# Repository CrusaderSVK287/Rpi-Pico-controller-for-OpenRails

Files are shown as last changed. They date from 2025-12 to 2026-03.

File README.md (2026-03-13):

# Rpi-Pico-controller-for-OpenRails
Raspberry Pi Pico custom HID controller for OpenRails. Basically I made a custom controller for openrails
using Rpi Pico board as the central microcomputer. Since the Rpi Pico has limited analog inputs, I had to cut some 
corners. This repository contains:

- Code for the Raspberry Pi Pico.
- CAD files with the controller design.
- Any manual or documentation I have done.

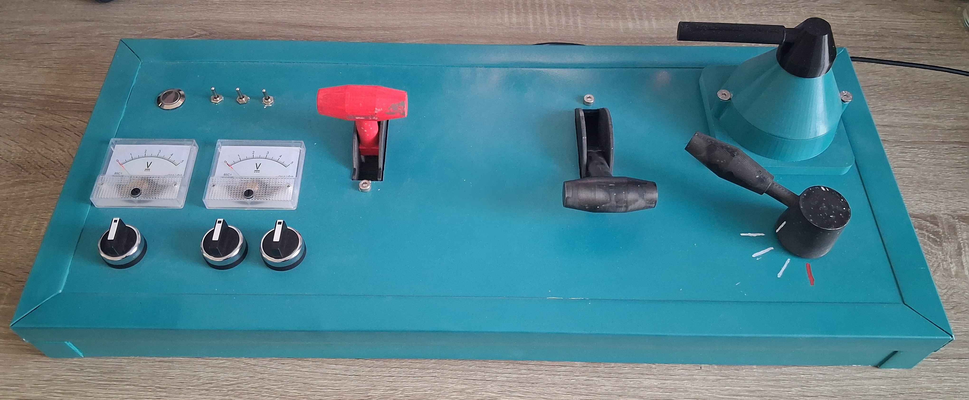
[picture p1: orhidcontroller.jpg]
Photo of the controller San Juan Mountains


## Supported controls

The controller's layout and looks is highly inspired by Czechoslovak locomotives from the 1970'-90' [For example the 754 series](https://cs.wikipedia.org/wiki/Lokomotiva_754)

### Analog controls
- Direction: the red lever, controlls the reverser of the train.
- Throttle : the black lever next to the direction lever, controls the throttle.
- Engine break: The small lever on top of the cone, controlls the engine break.

### Digital controls
- Train brake: the lever in the lower right corner. OpenRails implements train brake as analog, but due to the fact that Rpi Pico has only 3 analog inputs, I had to do this one digitaly and then just simulate it.
- Pantograph controls: turns on and off pantograph 1 and 2
- Headlights.
- Pause button: also acts as a switch TCS mode button if you run a red signal.
- View switch: 3-state switch, providing default cab view, outside static view and outside sidetrack "cinematic" view.
- Next station monitor switch.
- Track monitor switch.

# Aditional software that is needed

The OpenRails modification that includes code that interprets the HID controller is in [this repository](https://github.com/CrusaderSVK287/openrails).
<br>
In addition I made a simple app to test whether the controller is working properly, [here](https://github.com/CrusaderSVK287/OpenRails-HID-Tester).

## 🎥 Showcase

Click the image below to watch the demo. (Will redirect to youtube)

Watch the demo (https://www.youtube.com/watch?v=ZfCk2OY4qJo)

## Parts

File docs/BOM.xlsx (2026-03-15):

 | Count | Full name | Link | Notes
Bought parts
Voltmeter 5V | 2 | Panelový voltmeter DC s bočníkom - analógový | https://www.onpira.sk/tovar/panelovy-voltmeter-dc-s-bocnikom-analogovy/
3-state switch | 3 | MTS-103 3-state switch | https://techfun.sk/produkt/kovovy-trojpolohovy-prepinac-mts-103/ | I only needed 2-state switches but I had these already so I used them
Button | 1 | Just button switch | https://www.onpira.sk/tovar/tlacitkovy-spinac--16-19-mm-3a/
2 state rotary switch | 3 | rotary switch Ø22 mm OFF-ON | https://www.onpira.sk/tovar/cierny-otocny-spinac-22-mm-off-on/ | I did not use the plates, only the switches
4-state switch | 1 | 4-state switch | https://www.onpira.sk/tovar/prepinac-stvorpolohovy/ | Used for train brake, the black handle wasnt used
Potentiometer, rotary | 3 | B10K linear potentiometer | https://techfun.sk/produkt/potenciometer-rozne-typy-b1k-az-b500k/
Raspberry Pi Pico | 1
3D printed parts
Lever socket direction | 1 |  | https://github.com/CrusaderSVK287/Rpi-Pico-controller-for-OpenRails/blob/main/CAD/STL/LeverSlotDirection-Body.stl
Lever direction | 1 |  | https://github.com/CrusaderSVK287/Rpi-Pico-controller-for-OpenRails/blob/main/CAD/STL/LeverDirection-Body.stl
Lever socket throttle | 1 |  | https://github.com/CrusaderSVK287/Rpi-Pico-controller-for-OpenRails/blob/main/CAD/STL/LeverSlotThrottle-Body.stl
Lever throttle | 1 |  | https://github.com/CrusaderSVK287/Rpi-Pico-controller-for-OpenRails/blob/main/CAD/STL/LeverThrottle-Body.stl
Engine brake base | 1 |  | https://github.com/CrusaderSVK287/Rpi-Pico-controller-for-OpenRails/blob/main/CAD/STL/EngineBreakBase-Body.stl
Engine brake lever | 1 |  | https://github.com/CrusaderSVK287/Rpi-Pico-controller-for-OpenRails/blob/main/CAD/STL/EngineBreakLever-Body-v2.stl
Train brake | 1 |  | https://github.com/CrusaderSVK287/Rpi-Pico-controller-for-OpenRails/blob/main/CAD/STL/LeverTrainBreak-Body.stl
Chassis
Frame is made out of wooden boards nailed together and strenghtened by bars (not sure how to call it)
The top part is made out of some alluminium coated in plastic sheet found at junkyard
Other
Cables |  | Salvaged from old power supplies etc.
Screws and nuts |  | Random ones I found around the house that fit.
USB-A to microUSB cable |  | To power the rpi pico

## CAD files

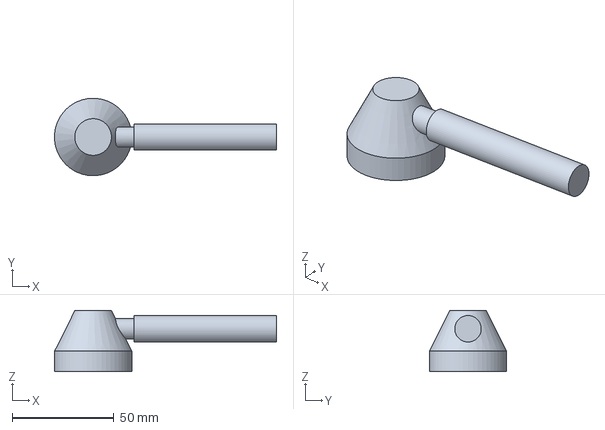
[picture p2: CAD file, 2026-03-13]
CAD/EngineBreakLever.FCStd
109.0 x 38.0 x 30.0 mm

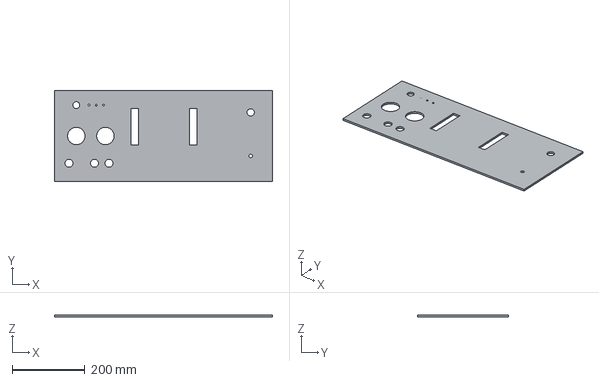
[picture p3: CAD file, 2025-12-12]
CAD/STEP/Base.step
600.0 x 250.0 x 5.00 mm

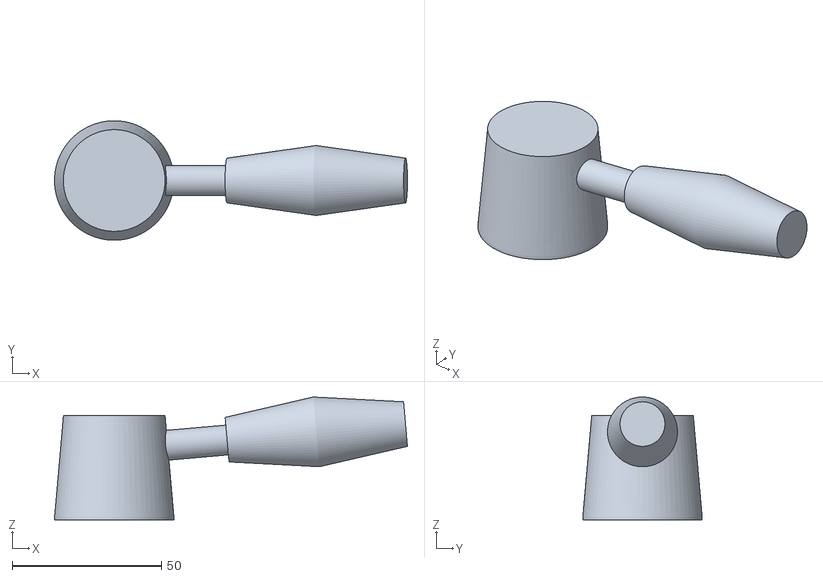
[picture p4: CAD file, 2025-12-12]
CAD/STL/LeverTrainBreak-Body.stl
118.2 x 40.0 x 41.2

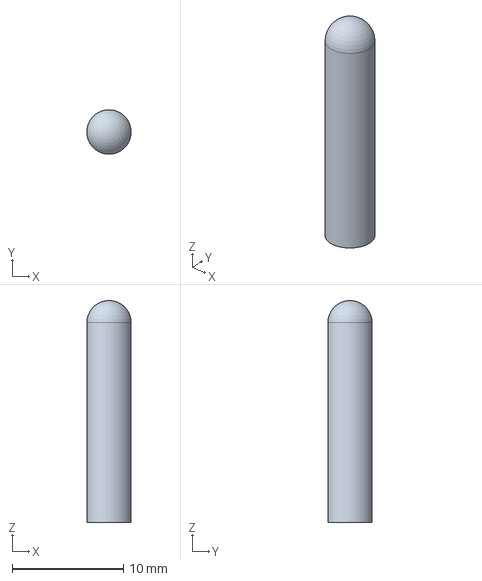
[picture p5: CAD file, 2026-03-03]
CAD/LeverSmall.FCStd
4.00 x 4.00 x 20.0 mm

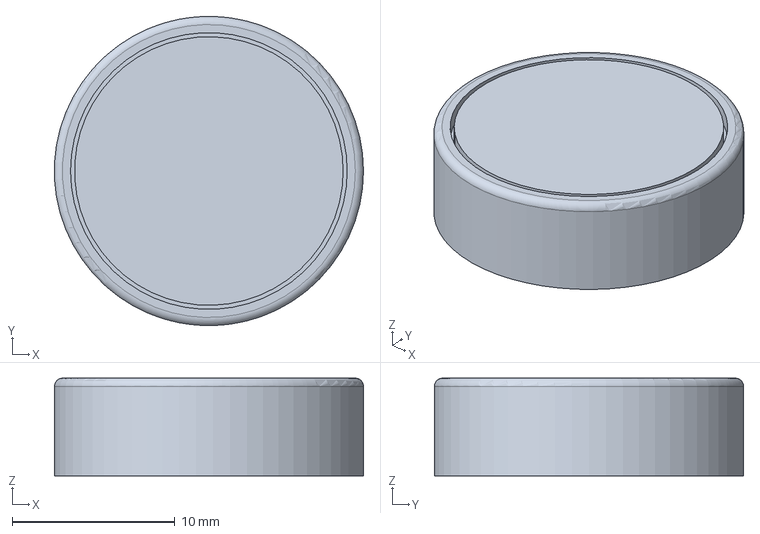
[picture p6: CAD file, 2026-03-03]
CAD/PauseButton.FCStd
19.0 x 19.0 x 6.00 mm

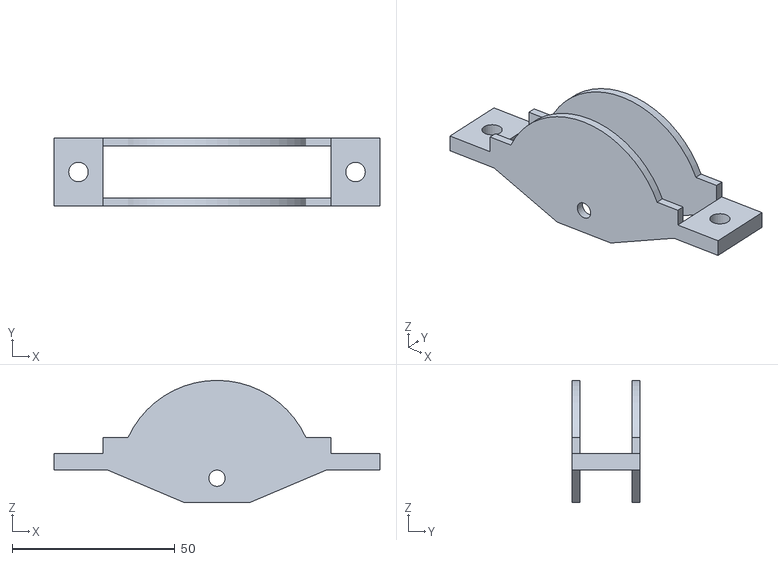
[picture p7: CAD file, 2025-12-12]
CAD/STL/LeverSlotDirection-Body.stl
100.0 x 21.0 x 37.5

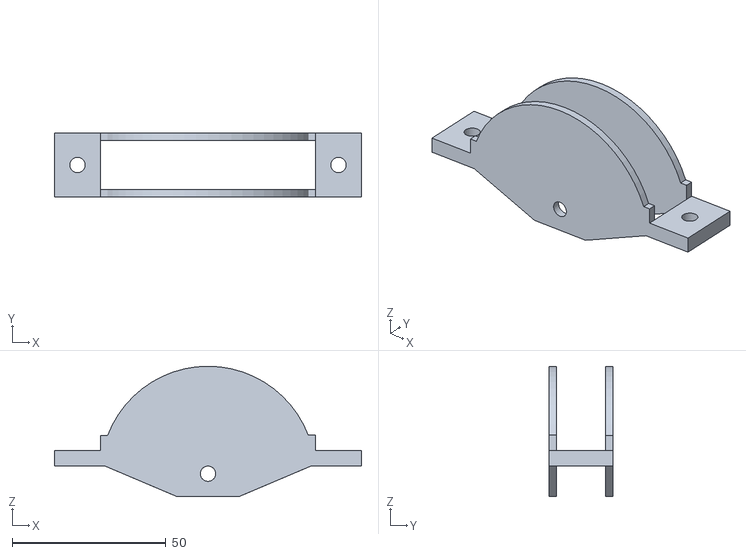
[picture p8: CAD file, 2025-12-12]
CAD/STL/LeverSlotThrottle-Body.stl
100.0 x 21.0 x 42.5

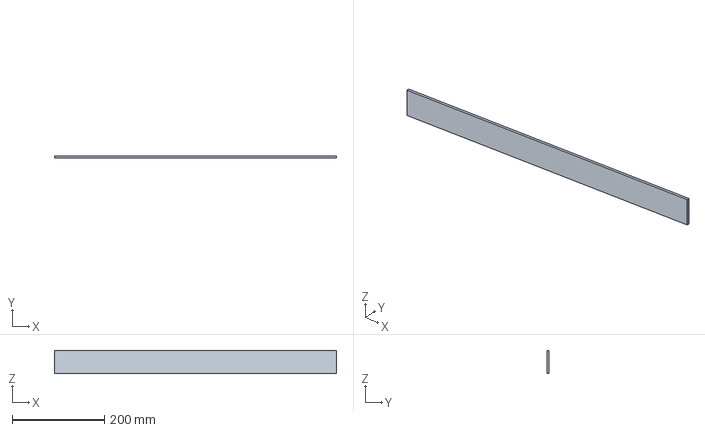
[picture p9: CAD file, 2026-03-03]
CAD/BasePanelFront.FCStd
610.0 x 5.00 x 50.0 mm

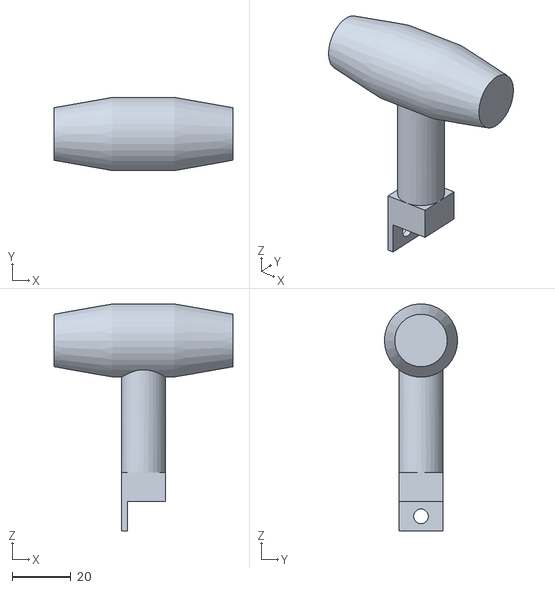
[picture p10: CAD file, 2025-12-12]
CAD/STL/LeverDirection-Body.stl
61.0 x 25.0 x 77.4

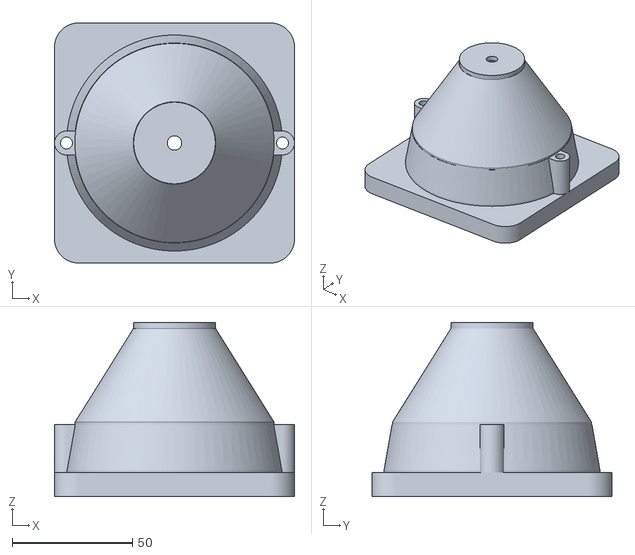
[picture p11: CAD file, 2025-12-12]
CAD/STL/EngineBreakBase-Body.stl
100.0 x 100.0 x 72.5

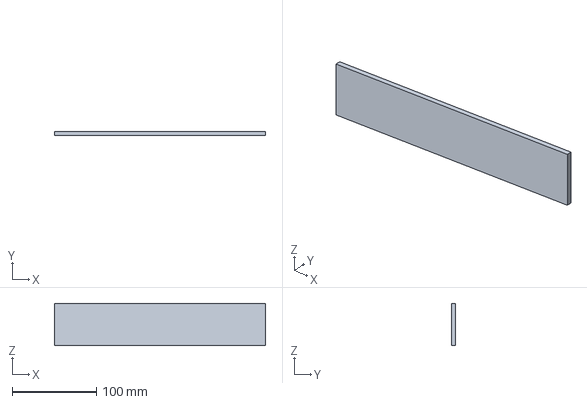
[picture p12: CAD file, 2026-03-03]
CAD/BasePanelSide.FCStd
250.0 x 5.00 x 50.0 mm

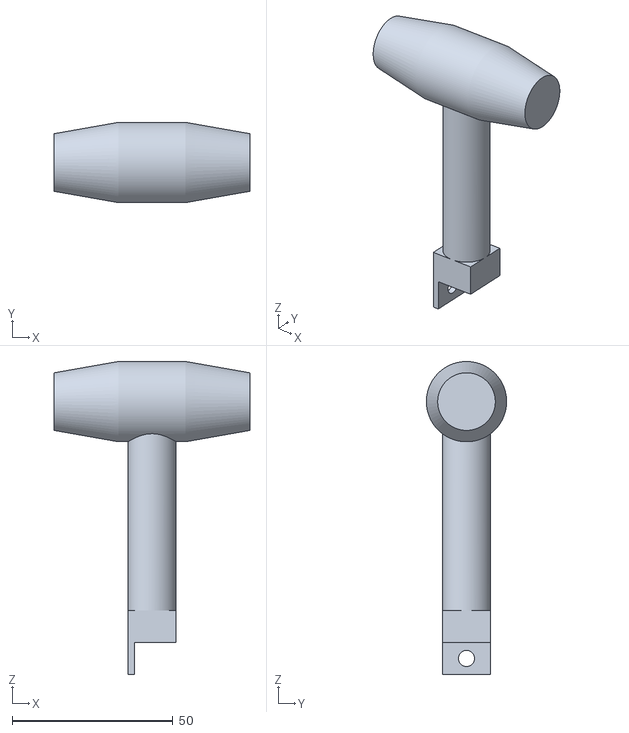
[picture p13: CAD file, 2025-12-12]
CAD/STL/LeverThrottle-Body.stl
61.0 x 25.0 x 97.5

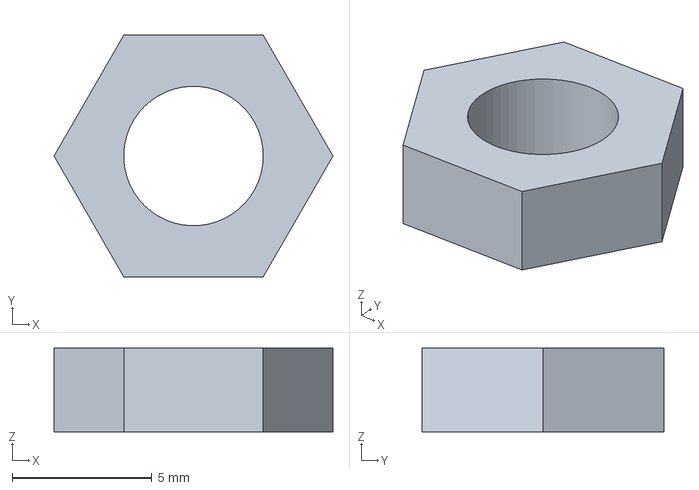
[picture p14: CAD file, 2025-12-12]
CAD/Nut5mm.FCStd
10.0 x 8.66 x 3.00 mm

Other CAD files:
CAD/OpenRailsControllerFullBody.FCStd
CAD/CustomPartsOnlyAssembly.FCStd
CAD/STL/EngineBreakLever-Body-v2.stl
CAD/OpenRailsController.FCStd
CAD/BasePanelBack.FCStd
CAD/Base.FCStd
CAD/EngineBreakBase.FCStd
CAD/LeverDirection.FCStd
CAD/LeverSlotDirection.FCStd
CAD/LeverSlotThrottle.FCStd
CAD/LeverThrottle.FCStd
CAD/LeverTrainBreak.FCStd
CAD/Potentiometer_B10K.FCStd
CAD/STL/CustomPartsOnlyAssembly.stl
CAD/STL/EngineBreakLever-Body.stl
CAD/Screw5mm.FCStd
CAD/SwtichRotary.FCStd
CAD/VoltMeter.FCStd

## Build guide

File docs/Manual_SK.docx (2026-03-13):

Manuál

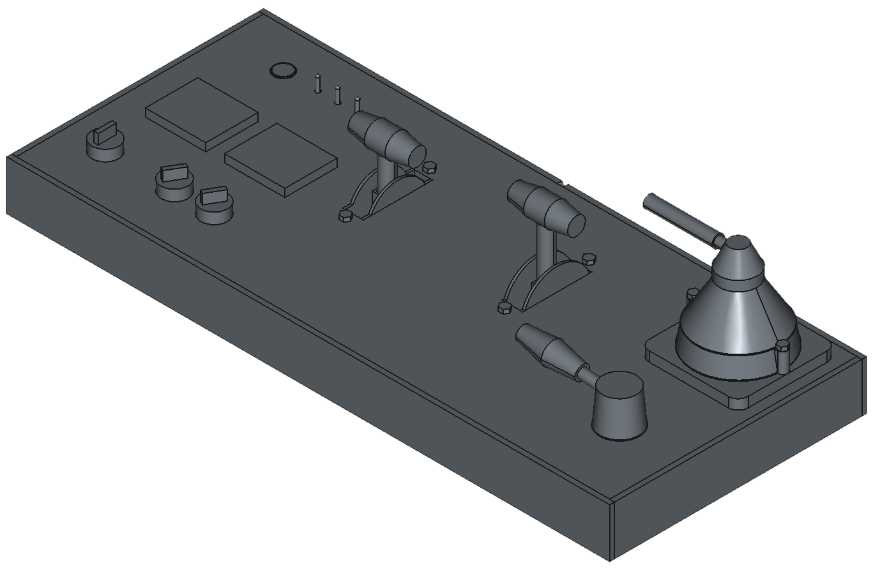
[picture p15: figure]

V 1.1 SK

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
1. Smerová páka
2. Plynová páka
3. Páka brzdy lokomotívy
4. Páka brzdy vlaku (prepínacia)
5. Svetlá
6. Pantograf 1
7. Pantograf 2
8. Tlačidlo pauza / prepnutie TCS módu
9. Pohľad
10. Staničný monitor
11. Traťový monitor

Príprava

Ovládač treba zapojiť do niektorého z USB-A portov na počítači pred spustením hry. Ak nebude ovládač pripojený ku počítaču pred spustením hry, hra ho nebude registrovať. Ak dôjde počas hry k odpojeniu ovládača, stačí ho zapojiť späť, modifikácia podporuje hot-plug zapojenie.

Odporúča sa pred spustením hry nastaviť smerovú páku (1) na neutrálnu hodnotu (do stredu), plynovú páku (2) na hodnotu 0 (k sebe), brzdu lokomotívy (3) na hodnotu 0 (vľavo), vlakovú brzdu (4) na hodnotu 2 (2. biela palička zvrchu) a obidva pantografy (6 a 7) nastaviť do polohy vypnuté.

Ovládanie

1. Smerová páka ovláda smer vlaku. Ak je posunutá smerom dole, vlak pôjde dozadu, ak je v neutrálnej polohe kolmo hore, vlak sa hýbať nebude, ak je zatlačená dopredu, vlak pôjde dopredu
2. Plynová páka zvyšuje výkon, ktorým vlak bude zrýchľovať.
3. Brzdná páka lokomotívy znižuje efektivitu plynu, je vhodná na mierne spomaľovanie a udržanie výkonu motora bez zrýchľovania.
4. Páka brzdy vlaku má 4 pozície (viď obrázok na ďalšej strane). Pozícia 1 (na obrázku) – brzda je uvoľnená, pozícia 2, brzda je zopnutá. Pozícia 3 je rovnaká ako 2 ale brzda pôsobí silnejšie. Pozícia 4 (červená) je núdzová brzda, brzdí najrýchlejšie, ale vlaku trvá značne dlhšie kým sa dá znova do pohybu po odbrzdení.

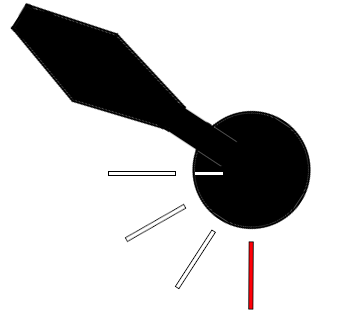
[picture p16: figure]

5. Svetlá – zapína alebo vypína svetlá.
6. Zapína alebo vypína pantograf do elektrickej siete. Po zapnutí pantografu sa na voltmetri nad prepínačom zobrazí hodnota ~3V. Voltmetre sú iba dekoračné, plus slúžia ako overenie funkčnosti zariadenia.
7. Pantograf 2
8. Tlačidlo pauzy. Pomocou tohto tlačidla sa dá pozastaviť hra, alebo pokračovať v hre, respektíve zatvoriť dialógové okno (viď obrázok).

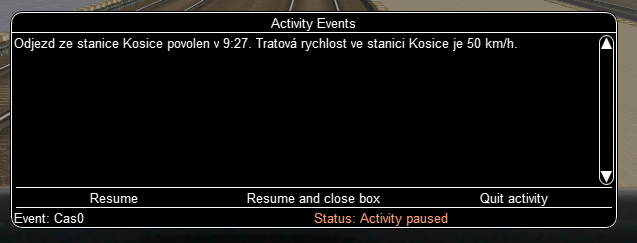
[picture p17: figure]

9. Trojpolohový prepínač pohľadu. Má 3 hodnoty. Neutrálna poloha (vzpriamená páčka) – pohľad vnútra kabíny. Poloha dopredu (páčka vpred) – statický pohľad na vlak zvonku. Poloha dozadu (páčka ku sebe) – panoramatický pohľad na vlak zvonku.
10. Zapína a vypína staničný monitor (viac o staničnom monitore neskôr)
11. Zapína a vypína traťový monitor (viac o traťovom monitore neskôr)

Ako pohnúť vlakom.

Prvý krok je zapnutie motora. Ak je vlak elektrický, je potrebné zapnúť pantografy (6 a 7). Pri dieselových vlakoch to nie je potrebné.

Ďalej je potrebné vypnúť brzdy nastavením brzdy lokomotívy (3) na hodnotu 0 a vlakovej brzdy (4) na polohu 1 (uvoľnená, viď obrázok vyššie). Ak hra bola spustená s vlakovou brzdou na polohe 1, treba ju pohnúť najprv na polohu 2 a potom späť na polohu 1 – limitácia modifikácie hry.

Smerová páka (1) musí byť nastavená do polohy vpred alebo vzad, podľa požadovaného smeru pohybu. Smerová páka bude reagovať iba v prípade, že plynová páka (2) je na hodnote 0.

Pomaly pridávať plyn pomocou plynovej páky (2). Vlak sa pomaly rozhýbe. Každá lokomotíva je iná, a reaguje inak na zmeny plynu.

Pozor: Ak pridáte plyn príliš rýchlo, vlaku sa môžu začať prešmykovať kolesá a stratí priľnavosť ku koľajisku. V takom prípade treba znížiť plyn až kým vlak znovu nezačne reagovať.

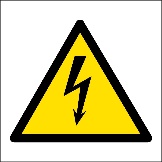
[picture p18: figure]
Electricity Safety Signs

Podobný problém môže nastať pri elektrických rušňoch. Ak je vlak príliš ľahký, oba pantografy sú vztýčené a pridáme plyn veľmi rýchlo, môže nastať preťaženie siete a vlak sa vypne (doslova mu vyhodia poistky). V takom prípade treba vypnúť vlak, stiahnuť pantografy, počkať, znovu ich zapnúť a pokračovať.

Staničný monitor

Staničný monitor je nástroj v dolnom ľavom rohu obrazovky, viď obrázok:

Obsahuje informácie o staniciach na trati, ich relatívnej vzdialenosti a časy príchodov a odchodov. Na príklade hore vidíme, že sme vyšli zo stanice Košice o viac než minútu skôr než sme mali (Departure – odchod, je 09:27:00, ale skutočný čas odchodu, actual, je 09:25:48). Na ďalšom riadku vidíme, že ďalšia je stanica Ťahanovce ktorá je 3,7 kilometra ďaleko od nás (Distance – vzdialenosť), a plánovaný príchod (Arrival) do tejto stanice je 09:31:00, odchod 09:32:00.

Traťový monitor

Traťový monitor je nástroj v hornom pravom rohu obrazovky, viď obrázok:

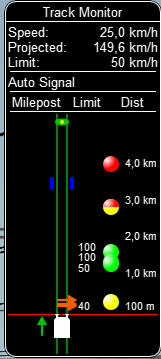
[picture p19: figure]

Traťový monitor ukazuje základné informácie o vlaku (nie vždy presné) a trati vpred. V hornej časti je speed – aktuálna rýchlosť vlaku, projected – predpokladaná rýchlosť vlaku po zrýchlení a limit – maximálna povolená/bezpečná rýchlosť.

Ďalej vidíme abstraktnú mapku trate, kde sú 2 dôležité body informácie. 1. sú semafory a stavy semaforov vpravo. Žltá gulička o 100 metrov, ďalej zelené guličky o kilometer a niečo, a na konci žlto červená gulička. Viac o semaforoch neskôr. Druhý bod informácie je stanica, na trati vyobrazená ako dve modré čiary paralelné ku trati. Ďalšia stanica sa teda nachádza približne 3,5 kilometra ďaleko.

Semafory

Semafory sú 4:

Zelený – nasledujúci blok koľajiska (po ďalší semafor) je voľný

Žltý – nasledujúci blok koľajiska je voľný, ale nasledujúci semafor je červený, odporúča sa spomaliť.

Červený – nasledujúci blok koľajiska je obsadený, stáť.

Žlto červený – nasledujúci blok koľajiska je voľný, ale je v ňom stanice v ktorej sa očakáva že daný vlak zastaví (alebo proste zastaví). Ďalší semafor je červený.

Ak je prejdený červený semafor, vlak automaticky zaradí núdzovú brzdu a dostane sa pod status SPAD – out of control. Kontrola vlaku sa tak zablokuje a odblokuje sa sama až potom, ako bude trať voľná.

Riešenie problémov

Ak pri spustení hry vyskočí hláška „HID Controller not enabled“, znamená to že zariadenie nie je pripojené alebo je nefunkčné.

Overenie funkčnosti zariadenia:

1. Rýchle overenie – zapojené zariadenie zapojiť do počítača, zapnúť pantograf. Ak voltmeter neukazuje ~3V, zariadenie je poškodené.
2. Pomocou testovacej aplikácie dostupej na adrese:

https://github.com/CrusaderSVK287/OpenRails-HID-Tester/releases

Aplikáciu treba zapnúť, pripojiť zariadenie a stlačiť tlačidlo „connect“.

Zdrojový kód modifikácie, manuálu a ďalšie súbory a dokumentácie sú na adrese:

https://github.com/CrusaderSVK287/Rpi-Pico-controller-for-OpenRails

ERRATA k 1.0

Prepnutie TCS módu

V prípade, že sa minie červené návestidlo, vlak sa automaticky prepne do TCS (Train control system) módu SPAD – out of control. Vlak tak prestane reagovať na všetky povely. V takom prípade treba postupovať takto:

- Počkať, kým vlak úplne zastaví
- 3 sekundy držať tlačidlo pauzy. To prepne TCS mód vlaku na manuálny (aktuálny TCS mód je viditeľný na traťovom monitore).
- Prepnúť smer jazdy dozadu
- Cúvať za návestidlo ktoré bolo prejdené
- Keď už sme v bezpečnej oblasti (pred návestidlom), prepnúť TCS mód späť na auto-signal, držaním tlačidla pauzy 3 sekundy.

TCS módy

Sú 2 hlavné TCS módy:

1. Auto-signal: predvolený mód, vlak sa riadi podľa návestidiel. V tomto móde sú zapnuté aj pomocné počítadlá ako vzdialenosť jednotlivých návestidiel alebo staníc od pozície vlaku
2. Manual: Ignorujeme návestidlá a stanice. Prejdením červeného návestidla sa vlak aj tak zastaví a prepne do TCS módu SPAD – out of control

SPAD – out of control je špeciálny typ TCS módu do ktorého sa dostaneme tak, že prejdeme červeným návestidlom. V tomto móde je vlak efektívne vypnutý a nebude reagovať na žiadne vstupy, až kým ho neprepneme do manuálneho módu.

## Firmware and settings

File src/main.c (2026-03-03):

#include "bsp/board.h"
#include "hardware/adc.h"
#include "tusb.h"

#include "sensors.h"
#include <hardware/gpio.h>
#include <stdint.h>

void send_input_report(const struct sensor_data *data)
{
    if (!tud_hid_ready()) return;
    if (!data) return;

    uint8_t report[8];

    // Analog axes (X, Y, Z)
    report[0] = (uint8_t)(data->throttle & 0xFF);        // low byte
    report[1] = (uint8_t)((data->throttle >> 8) & 0xFF); // high byte
    /* direction */
    report[2] = (uint8_t)(data->direction & 0xFF);       
    report[3] = (uint8_t)((data->direction >> 8) & 0xFF);
    /* brake (engine_break) */
    report[4] = (uint8_t)(data->engine_break & 0xFF);
    report[5] = (uint8_t)((data->engine_break >> 8) & 0xFF);

    // Digital byte 1: button + 5 two-state switches
    report[6] = (data->pause << 0) 
              | (data->track_monitor << 1)
              | (data->next_station << 2)
              | (data->headlights << 3)
              | (data->pantograph1 << 4)
              | (data->pantograph2 << 5);
    // Bits 6-7 are padding, left as 0

    // Digital byte 2: 3-state and 4-state switches
    // 3-state switch (bits 0-1), 4-state switch (bits 2-3)
    report[7] = (data->view & 0x03)                 // 3-state switch
              | ((data->train_break & 0x03) << 2);  // 4-state switch
    // Bits 4-7 are padding, left as 0

    tud_hid_report(0, report, sizeof(report));
}

// Required TinyUSB callback – called on setup
void tud_mount_cb(void) {
    // Device mounted
    if (tud_hid_ready()) {
        struct sensor_data data;
        sensors_report(&data);
        send_input_report(&data);       
    }
}

void tud_hid_report_complete_cb(uint8_t instance, uint8_t const* report, uint16_t len)
{
    struct sensor_data data;
    sensors_report(&data);
    send_input_report(&data);       
}

int main(void)
{
    board_init();
    tusb_init();

    // analog pin setup
    adc_gpio_init(APIN_THROTTLE);
    adc_gpio_init(APIN_DIRECTION);
    adc_gpio_init(APIN_ENGINE_BREAK);
    
    // digital pins setup
    // there is no PIN1_TRAIN_BRAKE
    const uint8_t pins[] = { PIN_PANTOGRAPH1, PIN_PANTOGRAPH2, PIN_HEADLIGHTS, PIN_TRACK_MONITOR, 
        PIN_NEXT_STATION,  PIN_PAUSE, PIN1_VIEW, PIN2_VIEW, PIN2_TRAIN_BRAKE,  
        PIN3_TRAIN_BRAKE,  PIN4_TRAIN_BRAKE   
    };
    const size_t pinCount = sizeof(pins) / sizeof(pins[0]);

    for (size_t i = 0; i < pinCount; i++) {
        uint8_t pin = pins[i];
        gpio_init(pin);
        gpio_set_dir(pin, GPIO_IN);
        gpio_pull_down(pin);
    }

    // initialisite the analog to digital converter
    adc_init();

    while (1)
    {
        tud_task();
    }
}

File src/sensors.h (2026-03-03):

#ifndef __SENSORS__
#define __SENSORS__

#include "tusb.h"
#include <stdint.h>

#define APIN_DIRECTION       26
#define APIN_THROTTLE        27
#define APIN_ENGINE_BREAK    28

#define PIN_PANTOGRAPH1     0
#define PIN_PANTOGRAPH2     1
#define PIN_HEADLIGHTS      2
#define PIN_TRACK_MONITOR   3
#define PIN_NEXT_STATION    4
#define PIN_PAUSE           8

#define PIN1_VIEW           6
#define PIN2_VIEW           7

// there is PIN1_TRAIN_BRAKE on the physical switch but its not used
#define PIN2_TRAIN_BRAKE    13
#define PIN3_TRAIN_BRAKE    14
#define PIN4_TRAIN_BRAKE    15

/* Structure to help with reading the sensor data */
struct __packed sensor_data {
    /* switches */
    uint8_t track_monitor;
    uint8_t next_station;
    uint8_t pantograph1;
    uint8_t pantograph2;
    uint8_t headlights;
    uint8_t pause;

    uint8_t view; // 3-state switch
    uint8_t train_break; // 4-state switch

    /* Analogs */
    uint16_t direction;
    uint16_t throttle;
    uint16_t engine_break;
};

/* Function that collects data from sensors and fills up data with them */
void sensors_report(struct sensor_data *data);

#endif

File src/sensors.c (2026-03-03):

#include "sensors.h"
#include <hardware/gpio.h>
#include <stdint.h>
#include "hardware/adc.h"

uint16_t read_analog_pin(uint8_t pin) 
{
    /*
     * direction    = pin 26 = ADC0 
     * throttle     = pin 27 = ADC1
     * engine break = pin 28 = ADC2
     */
    uint8_t input = pin == APIN_DIRECTION       ? 0 :
                    pin == APIN_THROTTLE        ? 1 :
                    pin == APIN_ENGINE_BREAK    ? 2 :
                    255;
    adc_select_input(input);
    return adc_read();
}

void sensors_report(struct sensor_data *data)
{
    if (data == NULL)
        return;

    /* Switches */
    data->pause         = gpio_get(PIN_PAUSE);
    data->track_monitor = gpio_get(PIN_TRACK_MONITOR);
    data->next_station  = gpio_get(PIN_NEXT_STATION);
    data->headlights    = gpio_get(PIN_HEADLIGHTS);
    data->pantograph1   = gpio_get(PIN_PANTOGRAPH1);
    data->pantograph2   = gpio_get(PIN_PANTOGRAPH2);

    /* 3-state switch */
    data->view = gpio_get(PIN1_VIEW) ? 1 :
                 gpio_get(PIN2_VIEW) ? 2 :
                                       0 ;
    /* 4-state switch */
    // No, the pins arent in the wrong order
    // 1. poloha - všetky kontakty sú rozopnuté
    // 2. poloha - zopnuté kontakty 0-1-2
    // 3, poloha - zopnuté kontakty 0-1-4
    // 4. poloha - zopnuté kontakty 0-1-3
    data->train_break = gpio_get(PIN2_TRAIN_BRAKE) ? 1 :
                        gpio_get(PIN4_TRAIN_BRAKE) ? 2 :
                        gpio_get(PIN3_TRAIN_BRAKE) ? 3 :
                                                     0 ;
    /* Analogs */
    data->throttle      = read_analog_pin(APIN_THROTTLE);
    data->direction     = read_analog_pin(APIN_DIRECTION);
    data->engine_break  = read_analog_pin(APIN_ENGINE_BREAK);
}

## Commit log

2025-06-29 Functioning HID Device is now recognized by windows as a HID device. Can use HIDsharp to read report data
2025-09-12 added base model
    [Base.FCStd, Base.step]
2025-09-15 Direction lever
    [Base.FCStd, LeverDirection.FCStd, LeverSlotDirection.FCStd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]
2025-09-19 Lever Throttle
    [Base.FCStd, LeverDirection.FCStd, LeverSlotThrottle.FCStd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]
2025-10-23 Design 1 done
    [Base.FCStd, EngineBreakBase.FCStd, EngineBreakLever.FCStd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]
2025-11-11 Exported STL files for 3D printing
    [CustomPartsOnlyAssembly.FCStd, CustomPartsOnlyAssembly.stl, EngineBreakBase-Body.stl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]
2025-11-20 added rotary switch and voltmeter to see the dimension aspect of it
    [Base.FCStd, OpenRailsController.FCStd, SwtichRotary.FCStd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]
2025-12-12 Refactoring: Split the code into several files boilerplace code like callback definitions that are empty for example were moved to separate file report and device descriptors are now in report.c/h an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
2025-12-12 Implemented sensor reading
2026-03-02 Small changes
    [Base.FCStd, BasePanelBack.FCStd, BasePanelFront.FCStd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]
2026-03-03 Redesign of engine break lever
    [EngineBreakLever-Body-v2.stl, EngineBreakLever.FCStd, OpenRailsController.FCStd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]
2026-03-03 added button and levers
    [Base.FCStd, LeverSmall.FCStd, OpenRailsController.FCStd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]
2026-03-13 some small change probably... I think I changed the inner diameter from 34 to 35mm
    [EngineBreakLever-Body-v2.stl, EngineBreakLever.FCStd]
2026-03-15 Added BOM to docs
    [BOM.xlsx]
